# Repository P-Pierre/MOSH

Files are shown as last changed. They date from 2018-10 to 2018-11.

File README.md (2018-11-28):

**ISS 2018 - 2019             
Mini-Projet MOSH            
Pierre PRIE & Mikita PRAKAPENKA**

Sommaire
========

1. Introduction au projet

	a. Présentation du sujet et des étapes clés
	
	b. Détail du contenue du dossier

2. Montage et développement du projet avec arduino

	a. Communication LoRa 
	
	b. Capteur de gaz connectée et gestion d'interruption
	
	c. Gestion d’énergie
	
	d. Interface Node-RED

3. Réalisation des PCBs pour le projet

	a. Réalisation de étage d’amplification du nanocapteur de gaz
	
	b. Réalisation du SHIELD arduino du projet

1.Introduction au projet
==========================

a. Présentation du sujet et des étapes clés
--------------------------------------------

   Dans le cadre de l’UF “MICRO-CONTRÔLEURS ET OPEN-SOURCE HARDWARE” en 5ème année spécialité “Innovative Smart Systems” nous avons conçus des PCBs visant à récupérer les données d’un nanocapteur de gaz et à les envoyer sur le serveur TTN grâce à la technologie LoRa. Nous avons découpé notre travail en plusieurs étapes : 

* Utiliser la puce RN2483 (LoRa) via l’Arduino UNO pour envoyer des données tests sur le serveur TTN. 

* Câbler et récupérer la réponse du capteur de gaz MQ-5.  

* Câbler un montage comparateur permettant de générer une interruption dès que la concentration en gaz mesuré par le MQ-5 dépasse un certain seuil. Le comparateur est de nature HW.  

* Établir une estimation de la consommation d’énergie du système.  

* Récupérer les données envoyées sur le serveur TTN via Node-RED pour réaliser un affichage graphique des données.  

* Réaliser un SHIELD avec l’ensemble des composants utilisés pour ce projet MOSH (connecteur avec la puce LoRa, avec le capteur de gaz MQ-5, le comparateur LM393, des LED de signalements…).  

* Réaliser une PCB pour l’étage d’amplification du nanocapteur de gaz conçu en salle blanche. Ce PCB est également équipé d’un cavalier et d’un mosfet IRF520 utilisés pour appliquer périodiquement une tension de décharge de 12V au borne du nanocapteur de gaz. 

* Notre SHIELD a finalement été modifié pour pouvoir y connecter la PCB du nanocapteur de gaz et de son étage d'amplification.  

Ce travail va nous permettre d’avoir un système complet qui récupère la réponse du nanocapteur, bien calibré avec le capteur MQ-5 et communiquant via LoRa, TTN et Node-Red. Le système gère la concentration dangereuse du gaz et envoie un message d’alerte, tout en ayant une interface graphique très lisible par l’utilisateur.   

b. Détail du contenue du dossier
--------------------------------

Ce projet comporte 3 dossiers différents :

* Le dossier KiCad regroupe les différents SHIELDS et PCBs réalisés. Les versions finales sont Capteur_Gaz_SB_for_SHield et SHield. Pour la PCB du nanocapteur de gaz et du shield du mini-projet respectivement.

* Le dossier arduino regroupe les codes arduino réalisés et utilisés sur la carte arduino UNO. Ce dossier dispose également d’un fichier.zip avec la librairie utilisé pour l’envoie de données avec LoRa.

* Un dossier IMG avec toutes les captures d'écrans et photos de notre projet.

2.Montage et développement du projet avec arduino	
===================================================

Pour réaliser notre code arduino, nous avons utilisés 2 librairies supplémentaires à celles présentes dans l’environnement arduino :

* La librairie <SoftwareSerial.h> présente dans les dossiers arduino.

* La librairie <rn2xx3.h> disponible à l’adresse : https://github.com/jpmeijers/RN2483-Arduino-Library. 

Cette librairie propose des fonctions d’initialisation et de communication de la puce LoRa avec le serveur TTN.

a. Communication LoRa
-----------------------

Afin d’établir la communication LoRa de la puce RN2483 avec l’antenne et donc le serveur TTN, on doit la connecter à l’Arduino UNO. Le pinout de la puce étant écrit sur son PCB on n’a qu’à connecter les pins correspondantes à l’Arduino ( Tx, Rx, RST, 3v3 et GND). 
Ensuite on suit la démarche du site TheThingsNetwork pour créer une application ainsi qu’un device sur cette application. L’application et le device sont défini par des identifiants : le DEVICE EUI et APPLICATION EUI. Lors de la création du device sur TTN nous avons choisit la méthode d’activation ABP. Le serveur TTN nous génère alors un “devAddr”, un “nwkSKey” et un “appSKey” qui sont utilisés dans notre code arduino pour identifier la puce LoRa et communiquer avec notre instance du serveur TTN.

Le code arduino est divisé en deux grandes parties, une partie void setup() qui  est exécuté une seul fois au démarrage de la carte et une partie void loop() qui s'exécute ensuite jusqu'à ce que la carte ne soit plus alimentée.

La partie void setup() nous permet principalement de tester et d’établir la connexion avec l’antenne LoRa, grâce à la fonction “initialize_radio” et de définir les interruptions. Nous reviendrons sur le fonctionnement des interruptions dans la partie suivante. La fonction “initialize_radio” renvoie différents messages d’initialisation sur le port série de l’ordinateur. Elle établit la connexion avec le serveur TTN grâce aux cléfs “devAddr”, “nwkSKey” et “appSKey”. En cas d'erreur un message spécifique est affiché sur le port série.

Dans la partie void loop(), l’envoie de donnée à la puce LoRa est réalisé avec la commande “myLora.tx(Donnée)”, la fonction découpe et envoie automatiquement les données en paquets de 2 caractères hexadécimale (8bits). 

Ces données sont alors lisibles directement sur TTN dans l’onglet “data” de notre device. Cependant ces données sont affichées sous leurs forme hexadécimale, il est nécessaire de coder un “Payload Formats” pour effectuer un affichage sous forme décimale. 
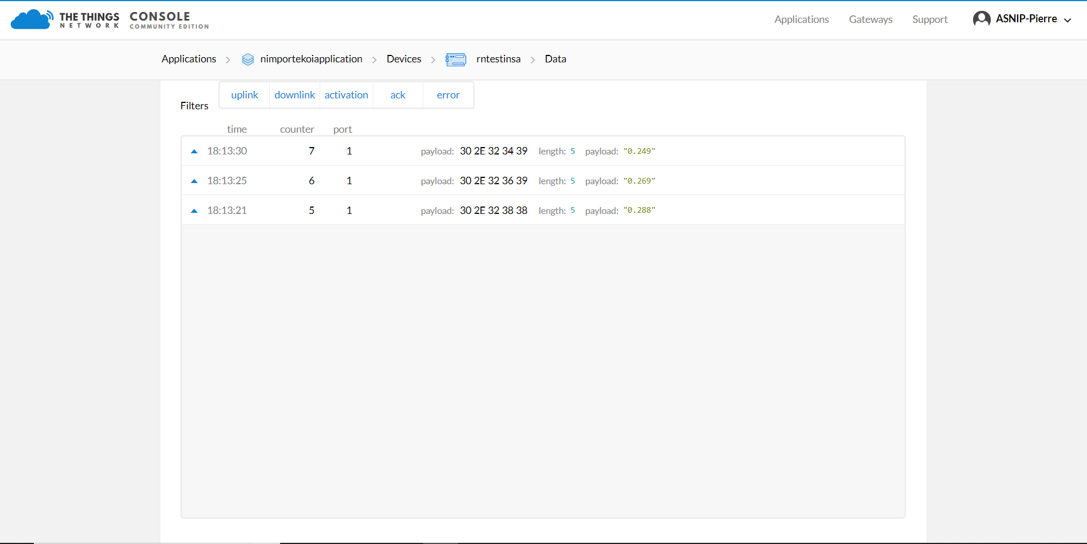
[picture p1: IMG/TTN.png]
Réception de messages sur TTN


b. Capteur de gaz connectée et gestion d'interruption
------------------------------------------------------

Le capteur de gaz MQ-5 possède une connexion de type “groove”. C’est un capteur de type analogique, on le connecte donc sur une des pins analogique. Le capteur est également relié à la masse et au 5V. Avant d’envoyer les données mesurées par le capteur de gaz, il faut les transformer en données digital. Pour cela, on divise la valeur lu par 1024 et on multiplie le résultat par 5. Cette formule est donnée dans la datasheet du capteur. Cette “transformation” aurait très bien pu être effectuée plus tard, comme juste avant l’affichage dans l’interface graphique de Node-RED. On note qu’une LED rouge clignote à chaque envoie de donnée via la puce LoRa.

Il est possible de définir des interruptions dans le void setup() du programme Arduino. Les interruptions consistent en une fonction qui sera exécutée à chaque fois que la condition d'interruption est réalisée. Pendant son exécution, le reste du programme est mis en pause. A la fin de son exécution, le programme reprend au début de la Void loop(). 
Une interruption est définie de la manière suivante : “attachInterrupt(1, gestionINT0UP, RISING)”. Ainsi quand un état montant est lu sur la pin 3, l'interruption se déclenche et exécute la fonction gestionINT0UP. Nous avons défini deux interruption différentes, une pour la lecture d’un état montant et une pour un état descendant.
Pour déclencher les interruptions, nous avons utilisé un AOP, le LM393, pour comparer la tension généré par le capteur de gaz MQ-5 et une tension seuil que nous avons défini grâce à un pont diviseur de tension. Ainsi dès que la tension du capteur de gaz MQ-5 dépasse ce seuil, un état haut est généré en sortie de l’AOP. A l’inverse quand la tension du capteur repasse sous le seuil, un état bas est généré. On note qu’une LED rouge s’allume et qu’un message d’alerte est envoyé sur le port série de l’ordinateur quand la tension du capteur de gaz se trouve au dessus du seuil. Dans le cas contraire, la LED s’éteint et un message de retour à l’état normal est envoyé sur le port série.
Utilisation du comparateur nous permet de générer des interruptions sans utiliser une comparaison logiciel qui serait testé à chaque exécution de la boucle.

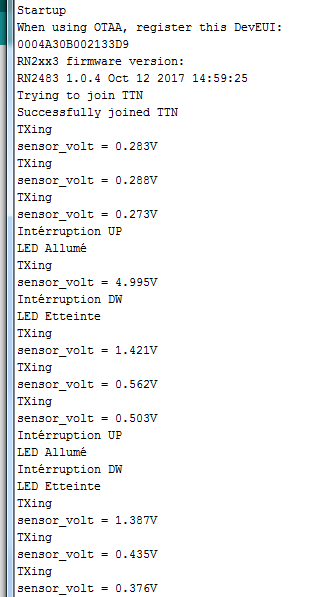
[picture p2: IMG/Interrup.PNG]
Communication avec le port série de l'ordinateur


c.   Gestion de consommation d’énergie
--------------------------------------

On peut estimer la consommation énergétique du système avec un Charger Doctor  qui se branche en série entre le port USB de l'ordinateur et le câble USB de l’Arduino. Il nous affiche la consommation moyenne de 0,280 A avec le capteur de gaz MQ-5 connecté. Or, dès qu’on déconnecte le capteur on tombe à  80mA de consommation. Cela s’explique par le fait que le capteur MQ-5 mesure la concentration des gaz en chauffant une résistance, ce qui n’est pas optimale pour la consommation énergétique. Avec le nanocapteur de gaz en revanche, on pourra espérer avoir une consommation d'énergie beaucoup plus basse. 

d.   Interface Node-RED
-----------------------

Afin de d'afficher les données mesurés par le capteur de gaz et envoyées sur le cloud (TTN), nous avons utilisé l'interface graphique Node-RED, très pratique. 
La première chose à faire, c’est d’installer l’interface sur votre PC. Pour ce faire, on a utilisé un guide de Node-RED pour Windows :  https://nodered.org/docs/platforms/windows. Après avoir installé l’interface on y accède via le terminal (commande “node-red”) et on ouvre l’adresse qu’il nous propose dans un  navigateur Web. Pour pouvoir manipuler les données de TTN, on doit installer une librairie “TheThingsNetwork” dédiée. 
A partir de maintenant on peut assembler l’interface, qui nous permettra d’afficher proprement les données du capteur. Tout d’abord on configure la partie “device” avec les identifiants de l’application TTN dédiée. Si tout a été bien saisi, on verra un voyant vert et le message “connected” à côté du “device”. Ensuite on va rajouter une fonction “get payload” à la suite du “device” qui va nous permettre de récupérer le message utile : msg = {value: msg.payload['payload']};return msg. Puis on connecte un afficheur “graphique en fonction du temps” et une "jauge"  à la suite de la fonction, pour pouvoir enfin afficher les données. En cliquant sur “Deploy” et puis sur le “dashboard” on affiche les données en temps réel dans un nouvel onglet. 
Sur les images suivantes vous voyez la réponse du capteur de gaz: normale au début, puis “rouge” à cause d’une concentration importante du gaz dangereux, et qui repasse en normale après. Vous y trouverez aussi notre interface Node-RED.
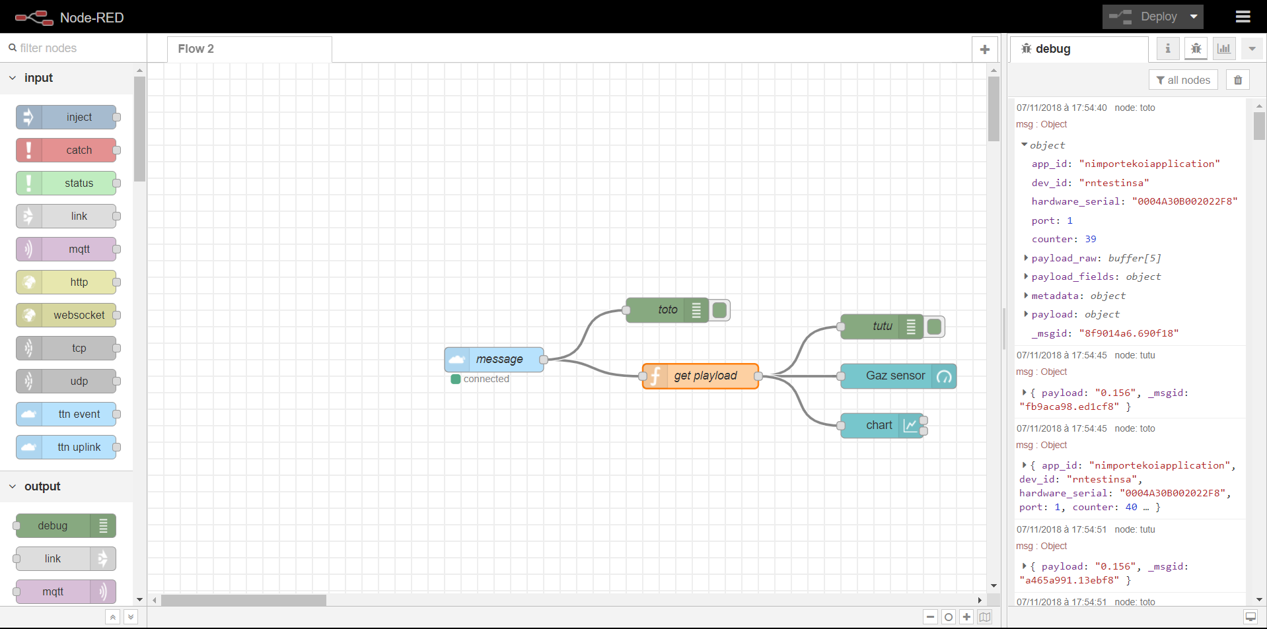
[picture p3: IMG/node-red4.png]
Code sous Node Red - bloc

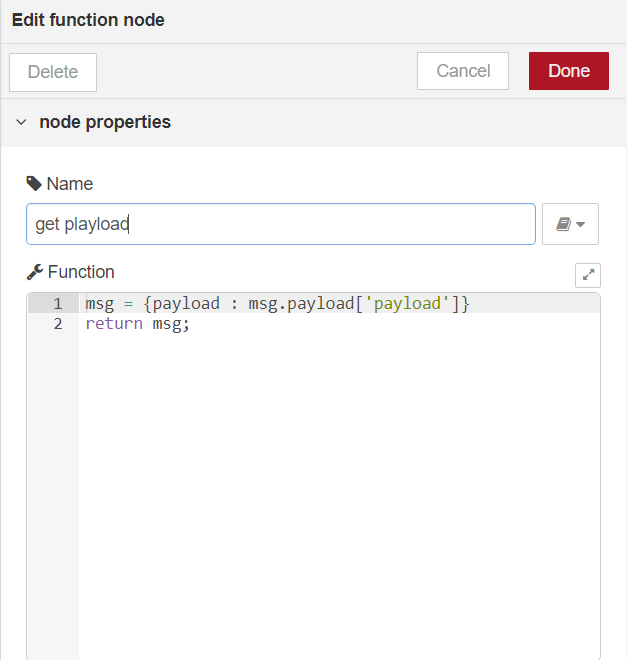
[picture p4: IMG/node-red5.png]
Code sous Node Red - Fonction payload

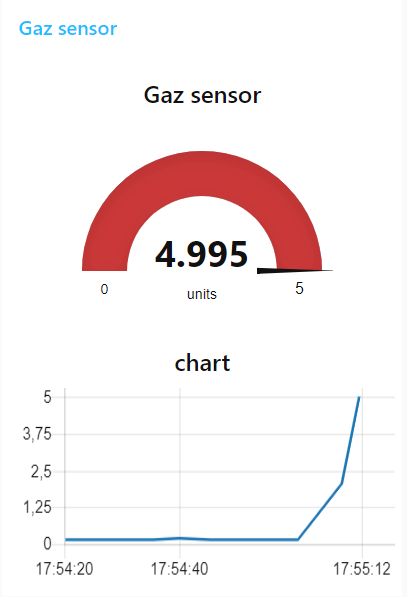
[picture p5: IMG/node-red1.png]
Graph 1

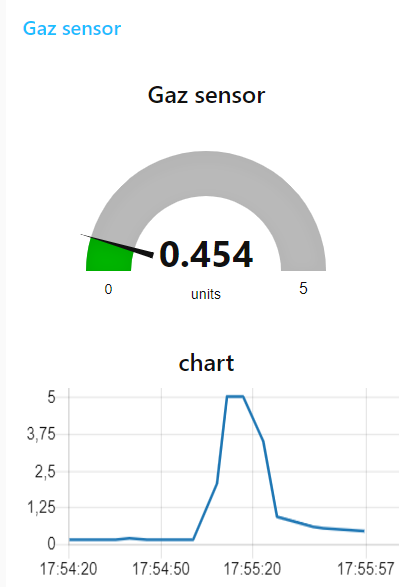
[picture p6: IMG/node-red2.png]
Graph 2

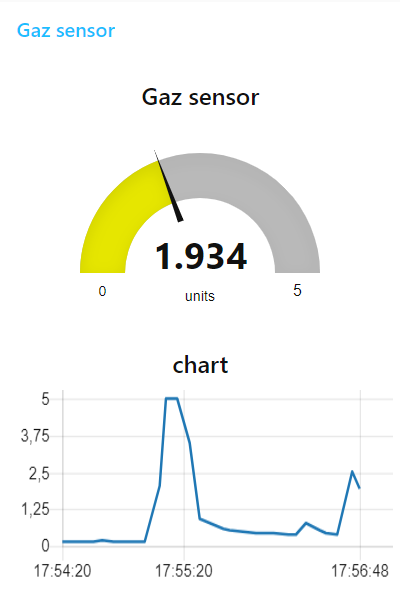
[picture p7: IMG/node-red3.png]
Graph 3


3.Réalisation des PCBs pour le projet
======================================

Pour réaliser l’ensemble de nos PCBs, nous avons utilisé le logiciel Open-Source Kicad qui permet de réaliser un circuit électrique et son routage. On commence par réaliser le circuit électronique, en définissant si nécessaire de nouvelles librairies pour les composants inexistant. On assigne ensuite une empreinte à chacun des composants avant de pouvoir réaliser le routage. 

a. Réalisation de étage d’amplification du nanocapteur de gaz
-------------------------------------------------------------

L’objectif était ici de réaliser le routage de l’étage d’amplification du nanocapteur de gaz, que nous avions testé et défini en TP. Nous avons également rajouté un mosfet IRF520 contrôlable par une pin de la carte arduino qui permettra d’appliquer une tension de décharge de 12V au borne du nanocapteur de gaz périodiquement. Un cavalier à été ajouté pour connecter la tension de décharge de 12V.
La PCB a été conçue pour venir se connecter sur le SHIELD arduino de notre projet MOSH.

b. Réalisation du SHIELD arduino du projet
------------------------------------------

L’ensemble de notre montage utilisé durant le mini-projet  a été routé sur un SHIELD pour Arduino UNO. Ce SHIELD comprend l’ensemble des LEDs, résistances, condensateurs, l’AOP, le connecteur du capteur de gaz MQ-5 ainsi que des connecteurs pour la puce LoRa et l’étage d’amplification du nanocapteur de gaz. L’ensemble de ces fichiers sont disponibles dans le dossier KiCad.

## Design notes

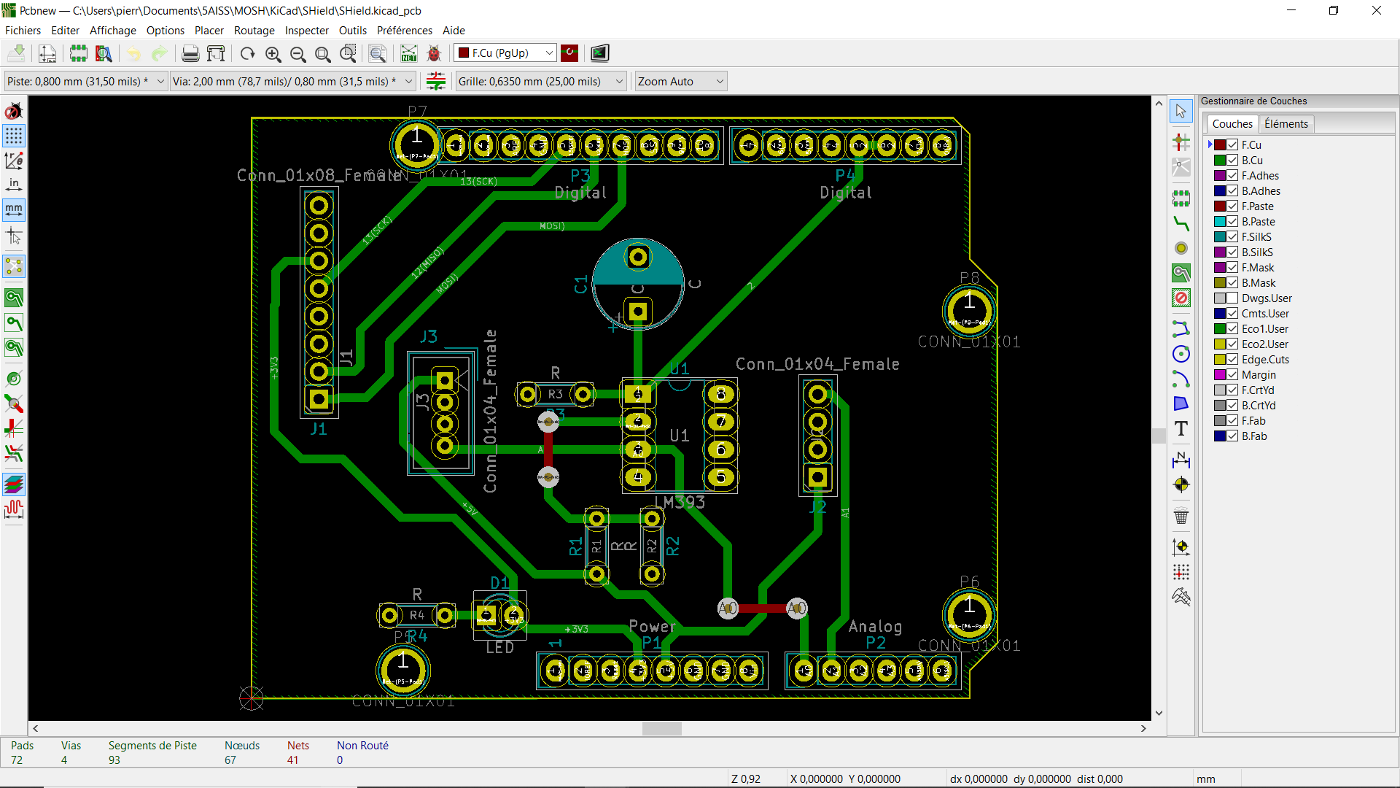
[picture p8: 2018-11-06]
KiCad/SHield/Before_modif_SB_Gaz_Sensor.png

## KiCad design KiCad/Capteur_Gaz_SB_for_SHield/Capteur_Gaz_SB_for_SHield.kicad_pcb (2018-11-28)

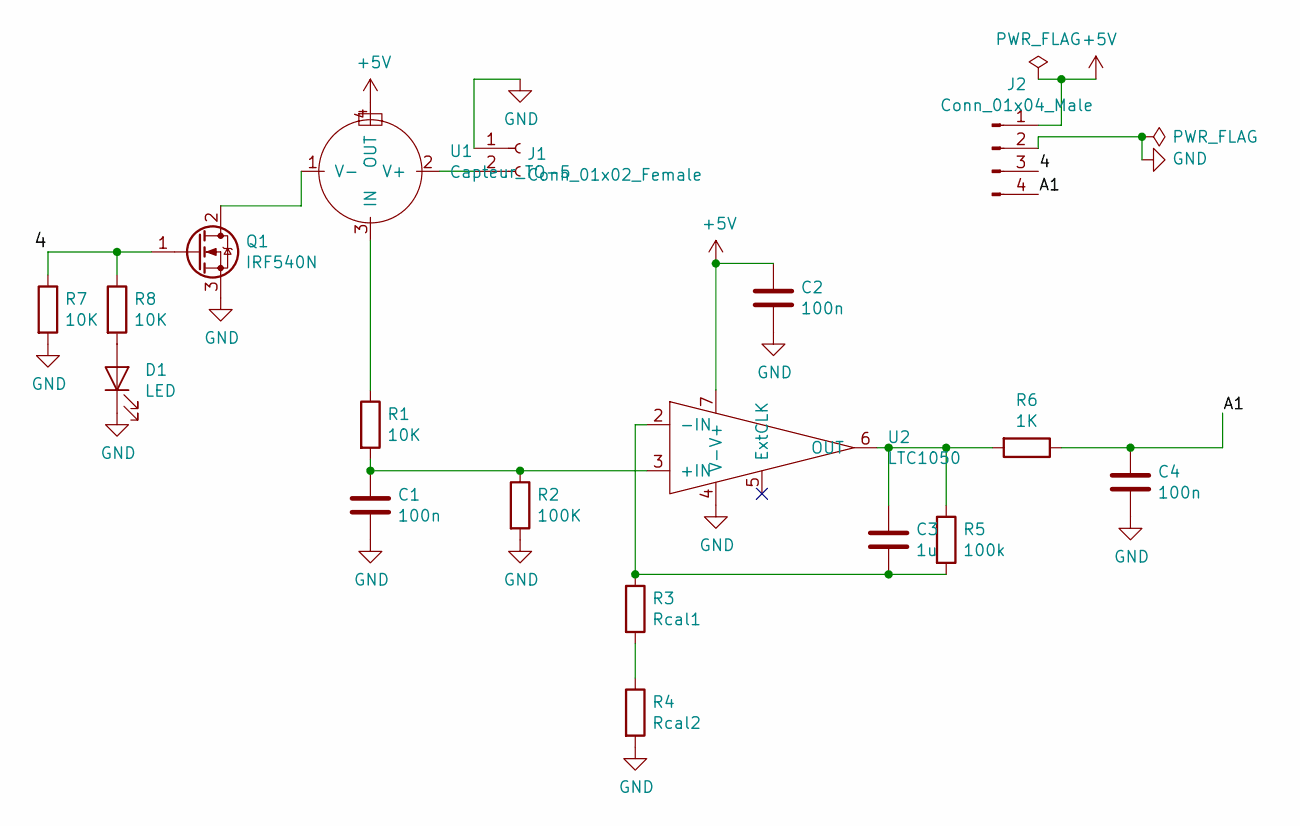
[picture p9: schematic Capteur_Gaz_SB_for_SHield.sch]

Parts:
C1, C2, C4: 100n; C_Rect_L7.0mm_W2.5mm_P5.00mm
C3: 1u; C_Rect_L7.0mm_W2.5mm_P5.00mm
D1: LED; LED_D3.0mm_FlatTop
J1: Conn_01x02_Female; PhoenixContact_MSTBVA_2,5_2-G-5,08_1x02_P5.08mm_Vertical
J2: Conn_01x04_Male; PinSocket_1x04_P2.54mm_Vertical
Q1: IRF540N; TO-220-3_Vertical
R1, R7, R8: 10K; R_Axial_DIN0204_L3.6mm_D1.6mm_P7.62mm_Horizontal
R2: 100K; R_Axial_DIN0204_L3.6mm_D1.6mm_P7.62mm_Horizontal
R3: Rcal1; R_Axial_DIN0204_L3.6mm_D1.6mm_P7.62mm_Horizontal
R4: Rcal2; R_Axial_DIN0204_L3.6mm_D1.6mm_P7.62mm_Horizontal
R5: 100k; R_Axial_DIN0204_L3.6mm_D1.6mm_P7.62mm_Horizontal
R6: 1K; R_Axial_DIN0204_L3.6mm_D1.6mm_P7.62mm_Horizontal
U1: Capteur_TO-5; TO-5-4
U2: LTC1050; DIP-8_W7.62mm_Socket_LongPads

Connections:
+5V: C2.1, J2.1, U1.4 (OUT), U2.7 (V+)
/4: J2.3, Q1.1 (G), R7.1, R8.1
/A1: C4.1, J2.4, R6.1
GND: C1.2, C2.2, C4.2, D1.1 (K), J1.1, J2.2, Q1.3 (S), R2.2, R4.2, R7.2, U2.4 (V-)
unnamed: C1.1, R1.2, R2.1, U2.3 (+IN)
unnamed: C3.1, R5.1, R6.2, U2.6 (OUT)
unnamed: C3.2, R3.1, R5.2, U2.2 (-IN)
unnamed: D1.2 (A), R8.2
unnamed: J1.2, U1.2 (V+)
unnamed: Q1.2 (D), U1.1 (V-)
unnamed: R1.1, U1.3 (IN)
unnamed: R3.2, R4.1

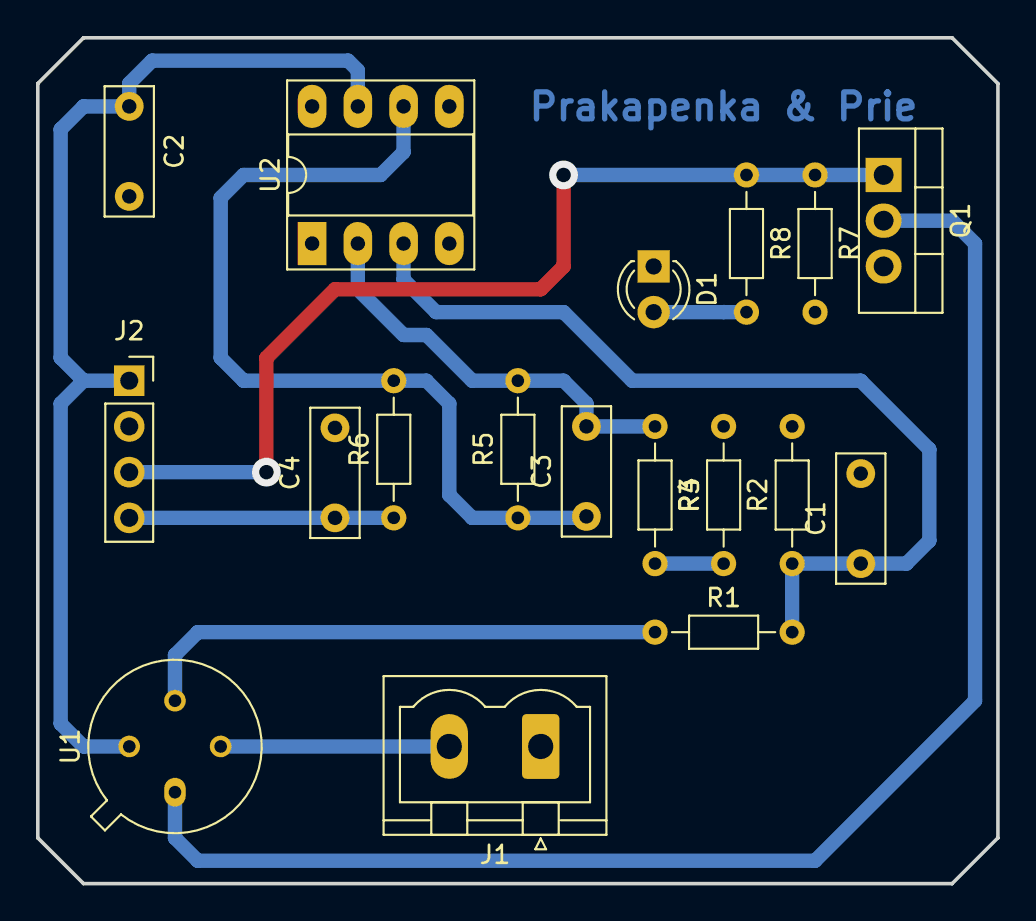
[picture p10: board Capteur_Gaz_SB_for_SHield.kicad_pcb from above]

Board: 2 copper layers, 53.3 x 47.0 mm, 18 parts (0 on the bottom side), 12 nets.

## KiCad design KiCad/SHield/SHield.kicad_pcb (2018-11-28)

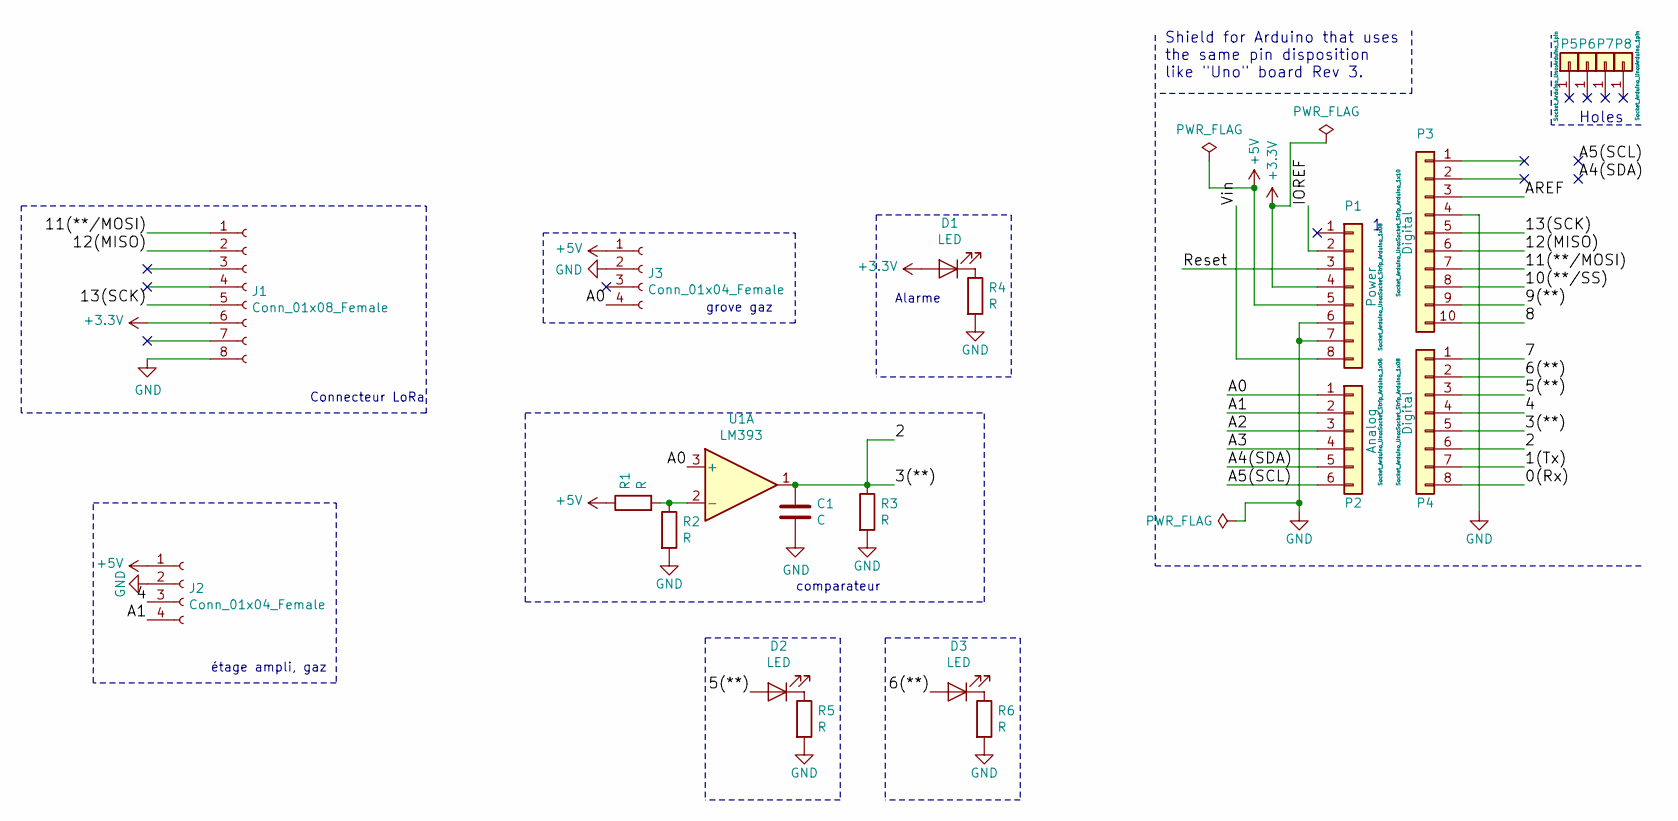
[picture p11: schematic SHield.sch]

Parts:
C1: C; CP_Radial_D8.0mm_P5.00mm
D1, D2, D3: LED; LED_D3.0mm_FlatTop
J1: Conn_01x08_Female; PinSocket_1x08_P2.54mm_Vertical
J2: Conn_01x04_Female; PinSocket_1x04_P2.54mm_Vertical
J3: Conn_01x04_Female; NS-Tech_Grove_1x04_P2mm_Vertical
P1: Power; Socket_Strip_Arduino_1x08
P2: Analog; Socket_Strip_Arduino_1x06
P3: Digital; Socket_Strip_Arduino_1x10
P4: Digital; Socket_Strip_Arduino_1x08
P5, P6, P7, P8: CONN_01X01; Arduino_1pin
R1, R2, R3, R4, R5, R6: R; R_Axial_DIN0204_L3.6mm_D1.6mm_P5.08mm_Horizontal
U1: LM393; DIP-8_W7.62mm_LongPads

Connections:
+3V3: D1.2 (A), J1.6, P1.4
+5V: J2.1, J3.1, P1.5, R1.1
/0(Rx): P4.8
/1(Tx): P4.7
/2: C1.1, P4.5, P4.6, R3.1, U1.1
/4: J2.3, P4.4
/5(**): D2.2 (A), P4.3
/6(**): D3.2 (A), P4.2
/7: P4.1
/8: P3.10
/9(**): P3.9
/10(**/SS): P3.8
/11(**/MOSI): J1.1, P3.7
/12(MISO): J1.2, P3.6
/13(SCK): J1.5, P3.5
/A0: J3.4, P2.1, U1.3 (+)
/A1: J2.4, P2.2
/A2: P2.3
/A3: P2.4
/A4(SDA): P2.5
/A5(SCL): P2.6
/AREF: P3.3
/IOREF: P1.2
/Reset: P1.3
/Vin: P1.8
GND: C1.2, J1.8, J2.2, J3.2, P1.6, P1.7, P3.4, R2.2, R3.2, R4.2, R5.2, R6.2
unnamed: D1.1 (K), R4.1
unnamed: D2.1 (K), R5.1
unnamed: D3.1 (K), R6.1
unnamed: R1.2, R2.1, U1.2 (-)

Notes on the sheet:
Holes
Shield for Arduino that uses the same pin disposition like "Uno" board Rev 3.
Connecteur LoRa
étage ampli, gaz
grove gaz
comparateur
Alarme

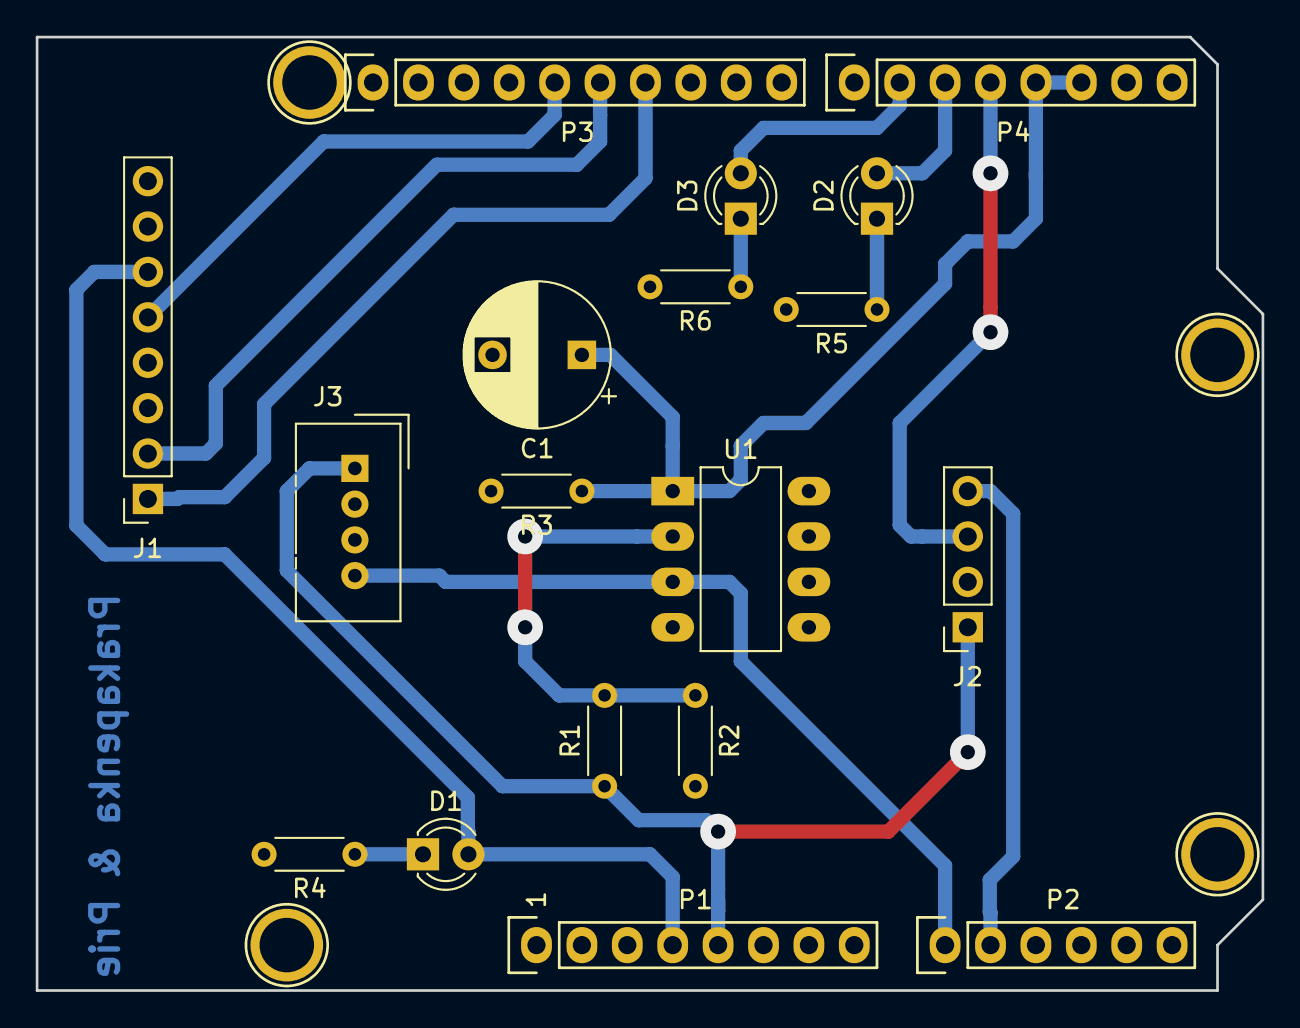
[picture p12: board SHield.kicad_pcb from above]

Board: 2 copper layers, 68.6 x 53.3 mm, 22 parts (0 on the bottom side), 16 nets.

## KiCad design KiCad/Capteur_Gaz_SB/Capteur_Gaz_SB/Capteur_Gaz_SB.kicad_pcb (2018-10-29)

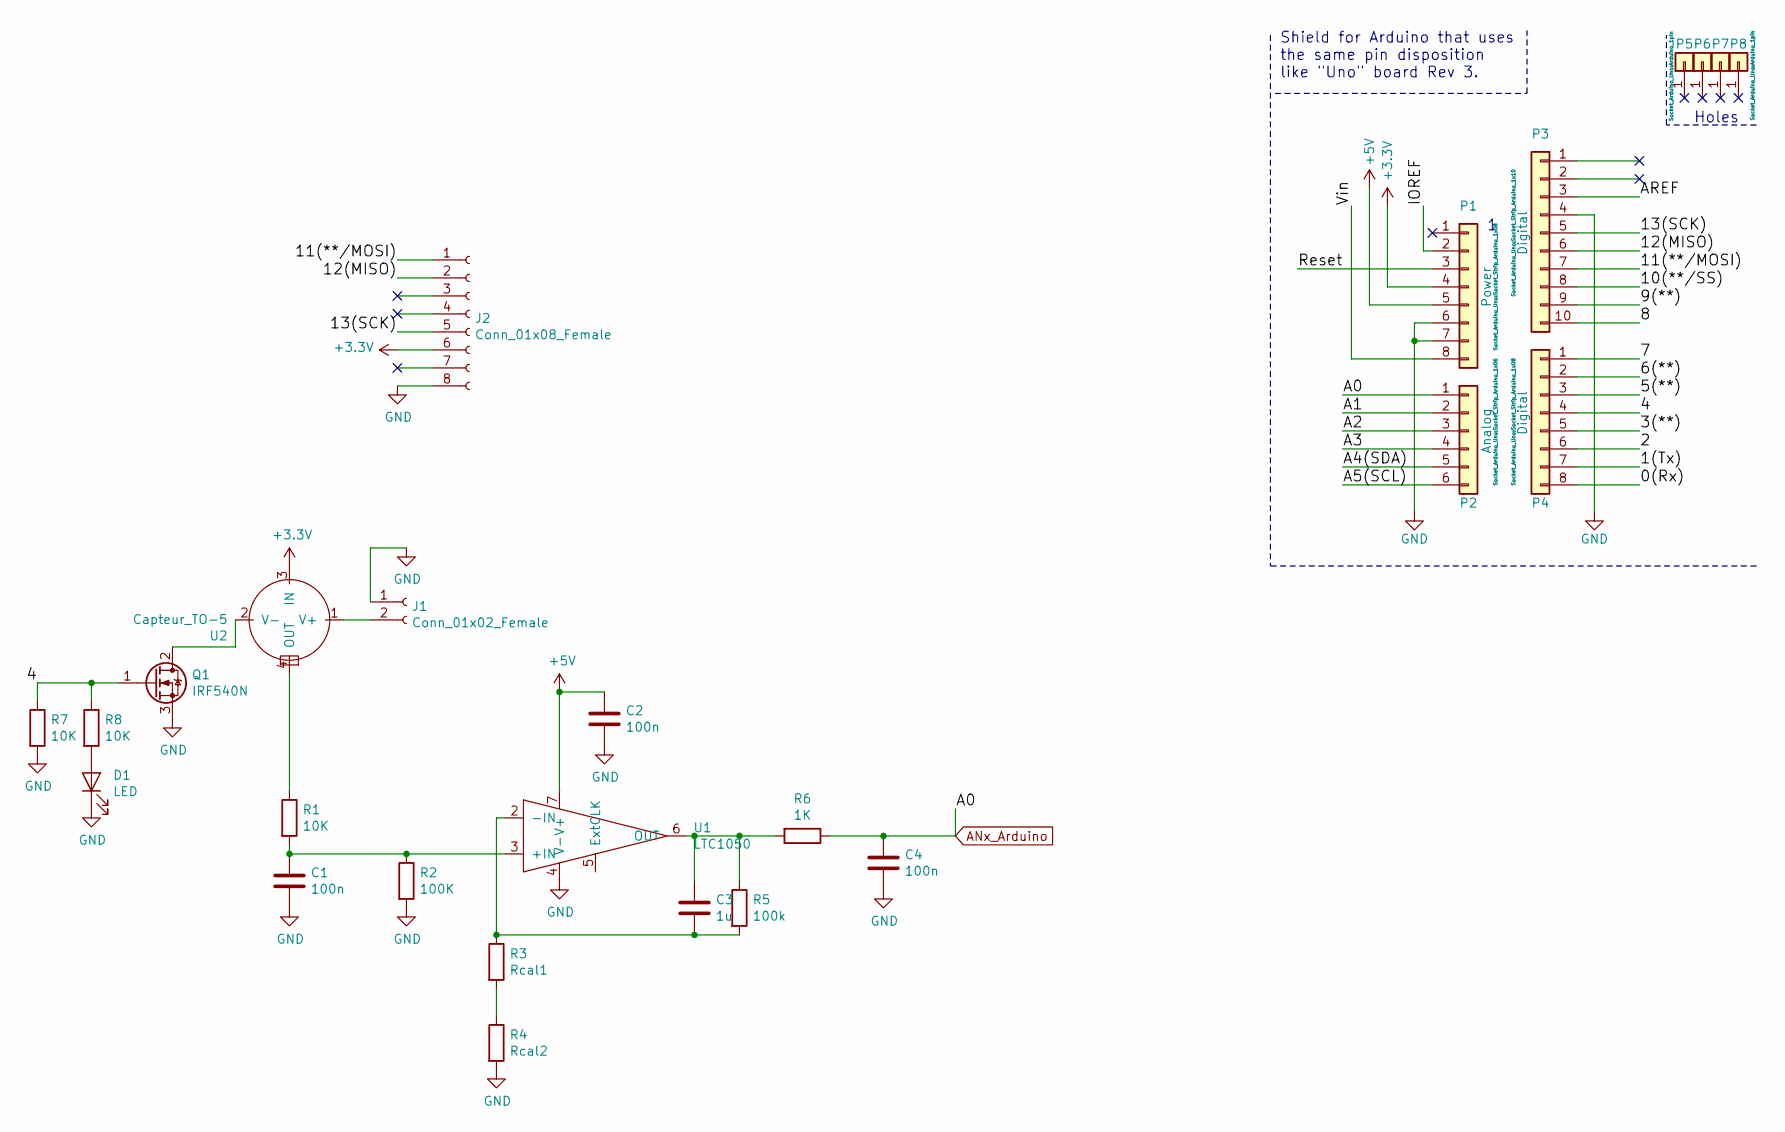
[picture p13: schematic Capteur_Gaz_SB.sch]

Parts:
C1, C2, C4: 100n; C_Rect_L7.0mm_W2.5mm_P5.00mm
C3: 1u; C_Rect_L7.0mm_W2.5mm_P5.00mm
D1: LED; LED_D3.0mm_FlatTop
J1: Conn_01x02_Female; PhoenixContact_MSTBVA_2,5_2-G-5,08_1x02_P5.08mm_Vertical
J2: Conn_01x08_Female; PinSocket_1x08_P2.54mm_Vertical
P1: Power; Socket_Strip_Arduino_1x08
P2: Analog; Socket_Strip_Arduino_1x06
P3: Digital; Socket_Strip_Arduino_1x10
P4: Digital; Socket_Strip_Arduino_1x08
P5, P6, P7, P8: CONN_01X01; Arduino_1pin
Q1: IRF540N; TO-220-3_Vertical
R1, R7, R8: 10K; R_Axial_DIN0204_L3.6mm_D1.6mm_P7.62mm_Horizontal
R2: 100K; R_Axial_DIN0204_L3.6mm_D1.6mm_P7.62mm_Horizontal
R3: Rcal1; R_Axial_DIN0204_L3.6mm_D1.6mm_P7.62mm_Horizontal
R4: Rcal2; R_Axial_DIN0204_L3.6mm_D1.6mm_P7.62mm_Horizontal
R5: 100k; R_Axial_DIN0204_L3.6mm_D1.6mm_P7.62mm_Horizontal
R6: 1K; R_Axial_DIN0204_L3.6mm_D1.6mm_P7.62mm_Horizontal
U1: LTC1050; DIP-8_W7.62mm_Socket_LongPads
U2: Capteur_TO-5; TO-5-4

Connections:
+3V3: J2.6, P1.4, U2.3 (IN)
+5V: C2.1, P1.5, U1.7 (V+)
/0(Rx): P4.8
/1(Tx): P4.7
/2: P4.6
/3(**): P4.5
/4: P4.4, Q1.1 (G), R7.1, R8.1
/5(**): P4.3
/6(**): P4.2
/7: P4.1
/8: P3.10
/9(**): P3.9
/10(**/SS): P3.8
/11(**/MOSI): J2.1, P3.7
/12(MISO): J2.2, P3.6
/13(SCK): J2.5, P3.5
/A1: P2.2
/A2: P2.3
/A3: P2.4
/A4(SDA): P2.5
/A5(SCL): P2.6
/AREF: P3.3
/IOREF: P1.2
/Reset: P1.3
/Vin: P1.8
ANx_Arduino: C4.1, P2.1, R6.1
GND: C1.2, C2.2, C4.2, D1.1 (K), J1.1, J2.8, P1.6, P1.7, P3.4, Q1.3 (S), R2.2, R4.2, R7.2, U1.4 (V-)
unnamed: C1.1, R1.2, R2.1, U1.3 (+IN)
unnamed: C3.1, R5.1, R6.2, U1.6 (OUT)
unnamed: C3.2, R3.1, R5.2, U1.2 (-IN)
unnamed: D1.2 (A), R8.2
unnamed: J1.2, U2.1 (V+)
unnamed: Q1.2 (D), U2.2 (V-)
unnamed: R1.1, U2.4 (OUT)
unnamed: R3.2, R4.1

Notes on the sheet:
Holes
Shield for Arduino that uses the same pin disposition like "Uno" board Rev 3.

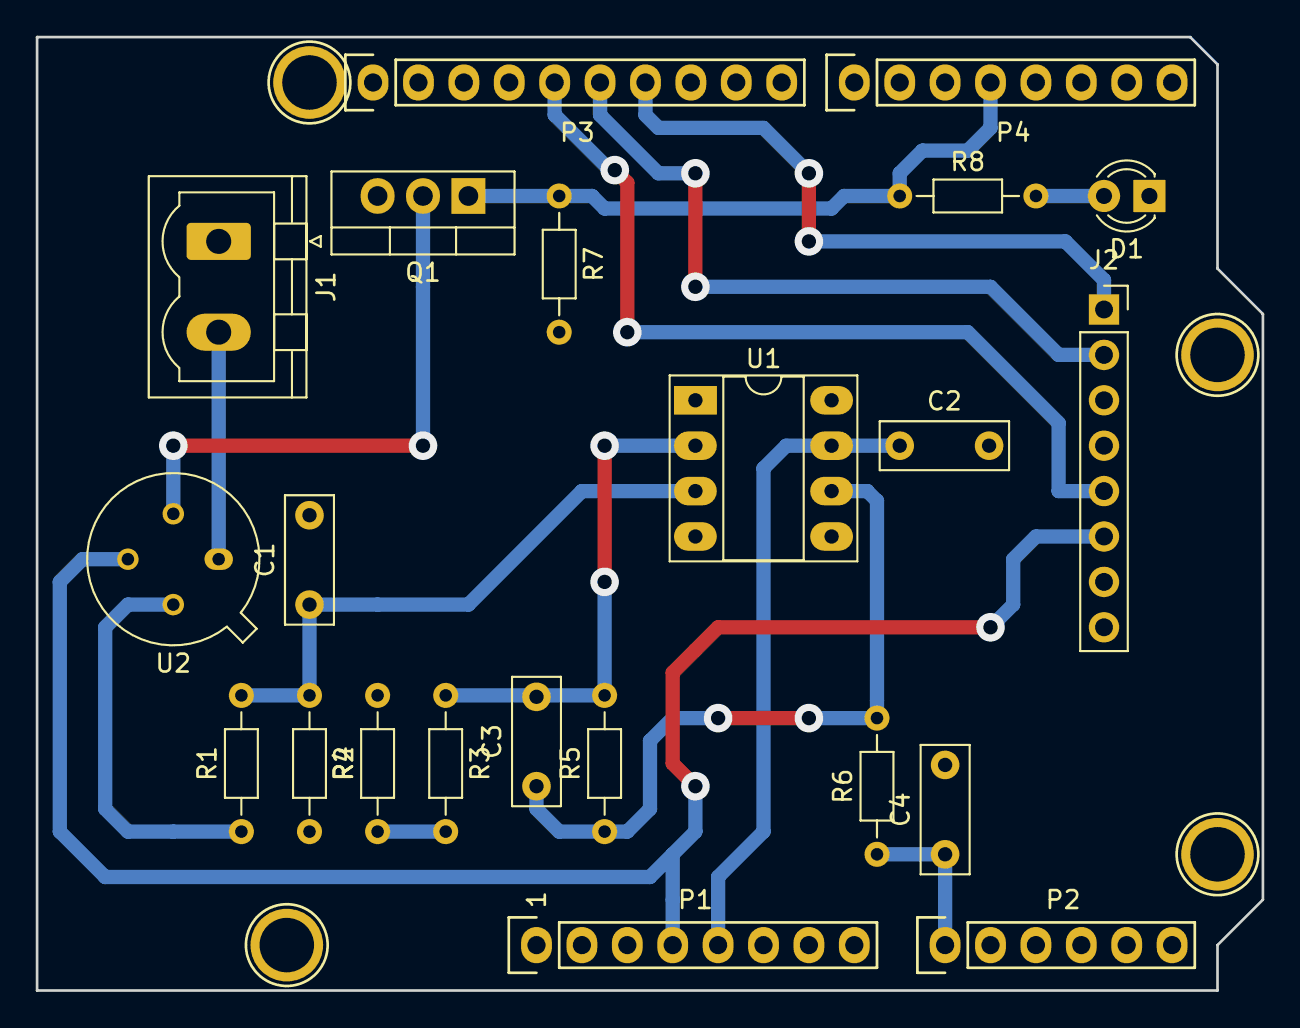
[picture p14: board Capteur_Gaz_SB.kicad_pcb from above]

Board: 2 copper layers, 68.6 x 53.3 mm, 26 parts (0 on the bottom side), 16 nets.

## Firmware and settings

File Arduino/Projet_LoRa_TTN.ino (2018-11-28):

#include <rn2xx3.h>
#include <SoftwareSerial.h>
#include <math.h>

SoftwareSerial mySerial(11, 12); // TX, RX
const int LED = 6;
const int LED2 = 5;
float sensorValue= 0;
int interup_secuUp= 0;
int interup_secuDw= 0;
int interup_secuCycle= 0;
String Res= "";

//create an instance of the rn2xx3 library,
//giving the software serial as port to use
rn2xx3 myLora(mySerial);

// the setup routine runs once when you press reset:
void setup(){
              //output LED pin
              pinMode(LED2, OUTPUT); //anciennement 13
              pinMode(LED, OUTPUT); 
              
              // attache l'interruption externe n°1 à la fonction gestionINT0UP()--0= pin2 et 1= pin3-- 
              attachInterrupt(1, gestionINT0UP, RISING); 
              // attache l'interruption externe n°1 à la fonction gestionINT0DW()
              attachInterrupt(0, gestionINT0DW, FALLING); 
              
              led_on();
            
              // Open serial communications and wait for port to open:
              Serial.begin(57600); //serial port to computer
              mySerial.begin(9600); //serial port to radio
              Serial.println("Startup");
            
              initialize_radio();
            
              //transmit a startup message
              myLora.tx("TTN Mapper on TTN Enschede node");
            
              led_off();
              delay(2000);
  }

void initialize_radio(){
    //reset rn2483
    pinMode(13, OUTPUT); 
    
    digitalWrite(13, LOW);
    
    delay(500);
    digitalWrite(13, HIGH);
  
    delay(100); //wait for the RN2xx3's startup message
    mySerial.flush();
  
    //Autobaud the rn2483 module to 9600. The default would otherwise be 57600.
    myLora.autobaud();
  
    //check communication with radio
    String hweui = myLora.hweui();
    
    while(hweui.length() != 16)
      {
        Serial.println("Communication with RN2xx3 unsuccessful. Power cycle the board.");
        Serial.println(hweui);
        delay(10000);
        hweui = myLora.hweui();
      }

    //print out the HWEUI so that we can register it via ttnctl
    Serial.println("When using OTAA, register this DevEUI: ");
    Serial.println(myLora.hweui());
    Serial.println("RN2xx3 firmware version:");
    Serial.println(myLora.sysver());
  
    //configure your keys and join the network
    Serial.println("Trying to join TTN");
    bool join_result = false;


      /*
       * ABP: initABP(String addr, String AppSKey, String NwkSKey);
       * Paste the example code from the TTN console here:
       */
    const char *devAddr = "26011CDB";
    const char *nwkSKey = "4A709BC513CF1D97416EE9273872FEA8";
    const char *appSKey = "38454B03AD26097929C9F252544AABBB";
    
      join_result = myLora.initABP(devAddr, appSKey, nwkSKey);

      while(!join_result)
        {
          Serial.println("Unable to join. Are your keys correct, and do you have TTN coverage?");
          delay(60000); //delay a minute before retry
          join_result = myLora.init();
        }
      Serial.println("Successfully joined TTN");
}


// la fonction appelée par l'interruption externe n°1
void gestionINT0UP() { 

  delayMicroseconds(10000);
   if (interup_secuCycle==0){ 
    
    if (interup_secuUp==0){
      digitalWrite(LED, 1);
      Serial.println("Intérruption UP "); 
      Serial.println("LED Allumé");
      interup_secuUp=2;
      }
    }
}
// la fonction d'interruption descendante

void gestionINT0DW() { 
    delayMicroseconds(10000);
    if (interup_secuCycle==0){

      if (interup_secuDw==0){
        Serial.println("Intérruption DW ");  
        Serial.println("LED Etteinte");
        digitalWrite(LED, 0);
        interup_secuDw = 2;
        interup_secuCycle=2;
        }
    }   
}

// the loop routine runs over and over again forever:
void loop(){
  
    delay(1000);

    sensorValue = analogRead(A0);
    Res = String(sensorValue/1024*5, 3);

    led_on();

    Serial.println("TXing");
    Serial.print("sensor_volt = ");
    Serial.print(Res);
    Serial.println("V");

    interup_secuCycle= 0;
    interup_secuUp= 0;
    interup_secuDw= 0;
    
    myLora.tx(Res); //one byte, blocking function
    led_off();
}

// la fonction d'allumage de la led branchée sur la pin 5

void led_on(){
  digitalWrite(LED2, 1);
}

// la fonction qui eteint la led branchée sur la pin 5

void led_off(){
  digitalWrite(LED2, 0);
}

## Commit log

2018-10-29 ajout du KiCad
    [SHield.kicad_pcb, SHield.sch]
2018-10-29 ajout shield capteur gaz SB
    [SHield.kicad_pcb, SHield.sch]
2018-10-29 ajout pour de bon
    [Capteur_Gaz_SB.kicad_pcb, Capteur_Gaz_SB.sch]
2018-10-29 fin shield SB
    [Capteur_Gaz_SB.kicad_pcb, Capteur_Gaz_SB.sch]
2018-11-06 modification et ajout carte pour capteur en salle blanche
    [Capteur_Gaz_SB.sch, Capteur_Gaz_SB_for_SHield.kicad_pcb, Capteur_Gaz_SB_for_SHield.sch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]
2018-11-07 Modifications deu shield, ajout de deux LED
    [Capteur_Gaz_SB_for_SHield.kicad_pcb, Capteur_Gaz_SB_for_SHield.sch, SHield.kicad_pcb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]
2018-11-07 ajout des fichiers arduino et lib utilisé. Ajout d'un dossier IMG
2018-11-27 Découpage des images
2018-11-28 Ajout du text sur les pcbs
    [Capteur_Gaz_SB_for_SHield.kicad_pcb, SHield.kicad_pcb]
2018-11-28 Version physique actuel de Kicad
